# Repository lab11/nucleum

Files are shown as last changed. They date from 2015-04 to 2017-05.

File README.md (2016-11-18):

Nucleum
====

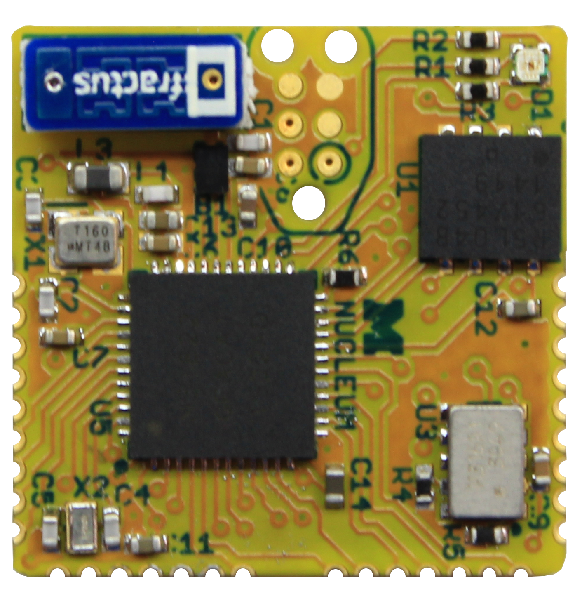
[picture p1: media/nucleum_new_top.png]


Nucleum is a ½ inch² drop-in sensor node module designed to enable rapid
prototyping of Bluetooth Low Energy embedded devices. 
The core of Nucleum is the NRF51822
SoC with an Arm Cortex M0 and BLE radio stack. Nucleum also includes an
antenna, 4 kilo-bytes of non-volatile FRAM memory, an RTC, and a tri-color LED.

Nucleum is designed to have two different usage patterns. First, three sides
of the device have castellated headers allowing Nucleum to be directly
soldered onto a carrier PCB. Nucleum handles all of the computation and
communication while the carrier board supplies power and attaches
sensors or other peripherals. In the second option, Nucleum can function
as a complete sensor node. On the bottom are pads for a regulator
and a battery. If needed, a peripheral or sensor board can be stacked on
top using the headers as a bridge.

History
-------

Nucleum is directly derived from [Atum](http://www.github.com/lab11/atum). It
changes the radio protocol to BLE and adds an on-board programmer. Like Atum, 
it is intended to be a building block for sensor platforms that only includes
the features that a sensor board needs.
Visit the [Atum](http://www.github.com/lab11/atum) page to read more about its 
origins.

Name
----

Nucleum is the latin accusative form of 'Nucleus' which, like [Atum](http://www.github.com/lab11/atum),
represents a basic building block of matter. The 'LE' in the spelling of Nucleum 
indicates its use as a Bluetooth Low Energy prototyping board, and the 'UM' at
the end of Nucleum represents Nucleum's development at the University of Michigan.

Usage
-----

To use the NRF51822, you should run bare metal code that is built around
the Nordic SDK and software BLE stack (known as a softdevice). We provide
some examples and drivers for the chips on the Nucleum board. For more information
on getting started please see software/README.md.

PCB
---

Nucleum PCBs are panelized into 5x8 panels. They are designed to be 
1mm thick to allow for easy soldering of the castellations on the edge of
the board.

If you use the battery and regulator on the bottom of the board, you will have
to populate a 0 Ohm resistor to select regulated voltage. The selection is between 1.8V
and 3.0V. Position A is 1.8V and position B is 3.0V. The 1.8V selection was included
because it significantly lowers power draw on the NRF51822, but at this voltage
the RTC and FRAM may not work. Please see the
[hardware pdf](https://github.com/lab11/nucleum/raw/master/hardware/nucleum/rev_a/nucleum.pdf)
to locate this resistor selector.
DO NOT populate both position A and B; this will short the battery.

Pin Out
-------

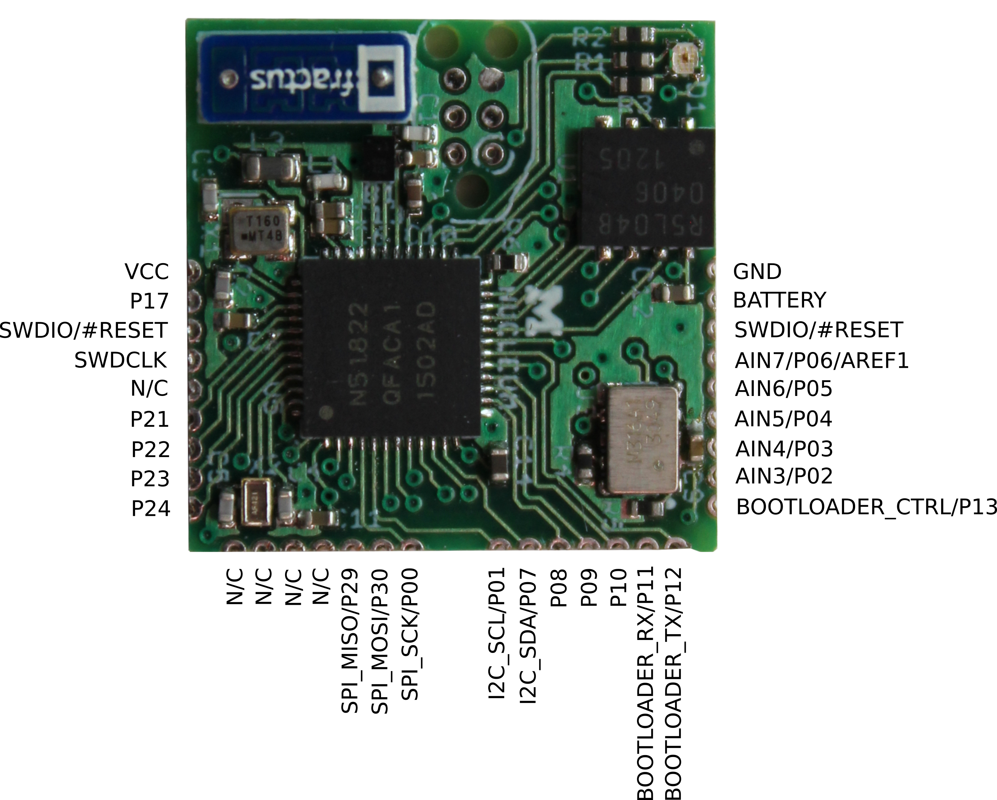
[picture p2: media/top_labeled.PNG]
Nucleum


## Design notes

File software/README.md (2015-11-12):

Getting Started on the nRF51822
===============================

This guide explains how to install the tools necessary to develop for
the nRF51822.

Install the Toolchain
---------------------

The NRF51822 run an ARM Cortex-M0, therefore the [gcc-arm-embedded](https://launchpad.net/gcc-arm-embedded/+download)
compiler will be used. Put the binaries for your platform in the bin directory.

On Linux you will also need 32 bit libs if you don't have them:

	sudo apt-get install lib32z1 lib32ncurses5 lib32bz2-1.0

Test that you have the toolchain by running:
	
	arm-none-eabi-gcc --version

Get a programmer setup
----------------------

Currently we support programming over SWD using a [tag-connect pogo pin header](http://www.tag-connect.com/catalog/6),
and a [j-link](https://www.segger.com/jlink-debug-probes.html) programmer.
We will soon provide a uart bootloader, however a j-link is still necessary to flash
the bootloader.

You should Download and install the [Segger flashing tools](https://www.segger.com/jlink-software.html)
for your platform.

Flash the example program
-------------------------
To flash the example program on to Nucleum:

    make flash 
	
This will automatically add the softdevice if it is not already
on the nRF51822.

For a complete set of commands including erasing and debugging, 
see the nrf51-pure-gcc-setup README.

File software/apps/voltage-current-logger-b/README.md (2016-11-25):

Log Current and Votlage Measurements with Nucleum Logger
========================================================

*This code only works with version B of the cvsense board*
If you want to use version A, then use the app voltage-current-logger

To use this logger:

1) Insert Battery
2) Make flash to update time
3) Insert SD Card
4) Deploy

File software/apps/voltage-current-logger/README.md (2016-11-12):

Log Current and Votlage Measurements with Nucleum Logger
========================================================

According to the creator:

> Yeah. You need to make flash
> Updates the time
> Order is
> - Insert battery
> - Make flash
> - Insert sd card
> - Deploy

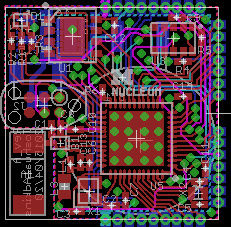
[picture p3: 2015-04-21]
hardware/nucleum/rev_a/nucleum_pcb.png

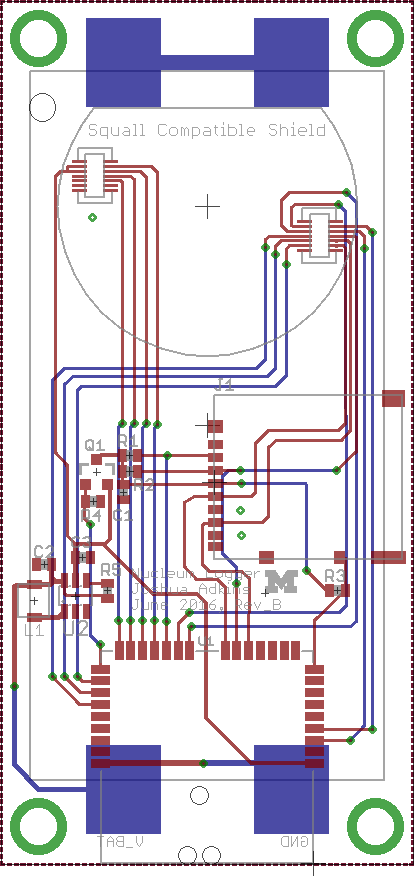
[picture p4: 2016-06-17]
hardware/nucleum_logger/rev_B/nucleum_logger_pcb.png

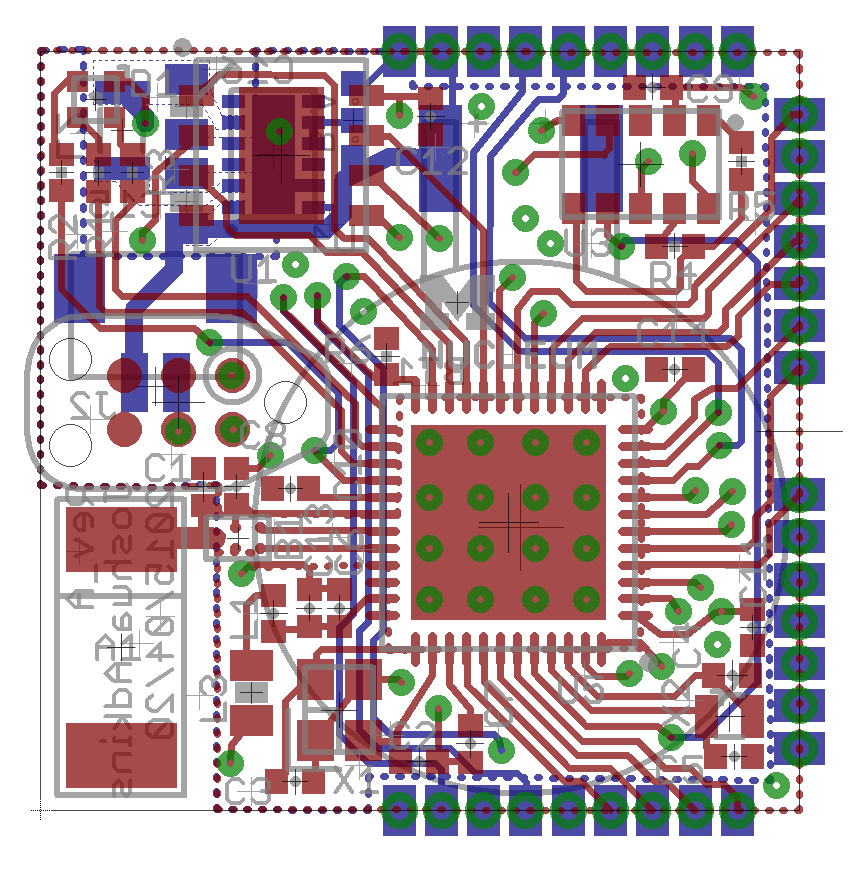
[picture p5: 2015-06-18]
media/nucleum_pcb.png

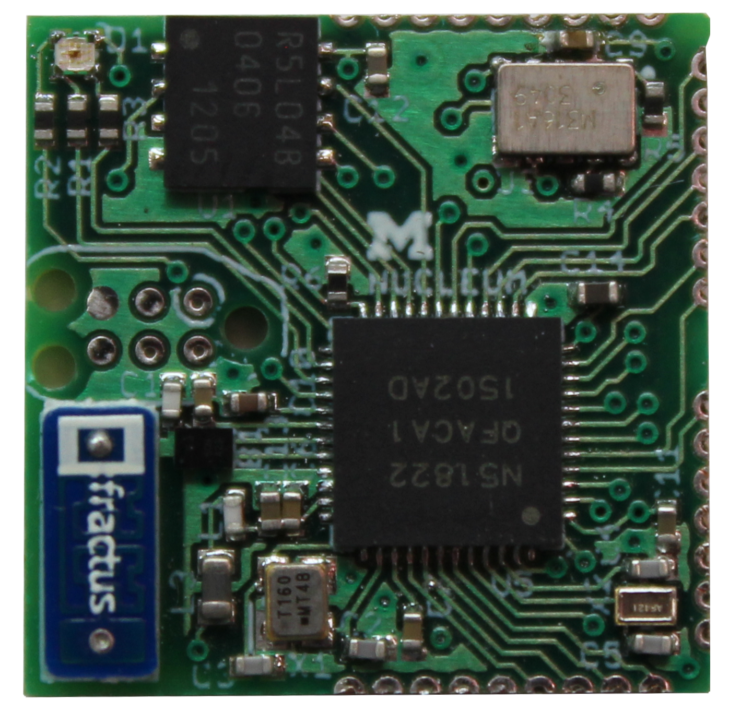
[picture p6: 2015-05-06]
media/nucleum.PNG

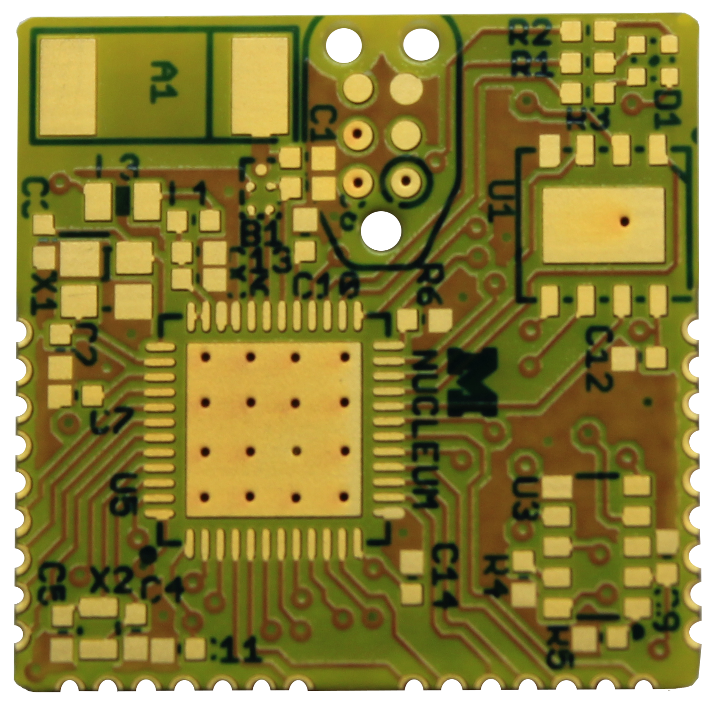
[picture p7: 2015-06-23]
media/nucleum_new.png

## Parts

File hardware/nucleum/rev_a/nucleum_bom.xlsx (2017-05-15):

Qty | Part | Value | Device | Package | DIGIKEY | MOUSER | NEWARK | RICHARDSON_RFPD
1 | A1 | FRACTUS-2.4GHZ-FR05-S1-N-0-102 | FRACTUS-2.4GHZ-FR05-S1-N-0-102 | FRACTUS-ANTENNA-FR05-S1-N-0-102 |  |  |  | FR05-S1-N-0102B
1 | B1 | BAL-NRF01D3 | BAL-NRF01D3 | BAL-NRF01D3 | 497-13637-1-ND | 511-BAL-NRF01D3
1 | DNP | ML-1220/F1AN | ML-1220/F1AN | ML-1220/F1BN | P663-nd | 658-ML-1220/F1BN
1 | C1 | 0.8pF | CAPACITOR | 0402_CAP | 490-6269-1-ND
4 | C2, C3, C4, C5 | 12pF | CAPACITOR | 0402_CAP | 490-6197-1-ND
2 | C6, C7 | 1nF | CAPACITOR | 0402_CAP | 490-1303-1-ND
1 | C8 | 2.2nF | CAPACITOR | 0402_CAP | 490-5419-1-ND
1 | C9 | 10nF | CAPACITOR | 0402_CAP | 445-1260-1-ND
1 | C10 | 47nF | CAPACITOR | 0402_CAP | 445-1264-1-ND
2 | C11, C12 | 0.1uF | CAPACITOR | 0402_CAP | 445-1265-1-ND
1 | C13 | 1uF | CAPACITOR | 0402_CAP | 445-4998-1-ND
1 | C14 | 4.7uF | CAPACITOR | 0402_CAP | 445-5947-1-ND
2 | DNP | 10uF | CAPACITOR0603_CAP | 0603_CAP | 490-7316-1-ND
1 | D1 | SML-LX0404SIUPGUSB | SML-LX0404SIUPGUSB | 1MM_SQ_4PAD | 67-2125-1-ND
1 | DNP | SH_MALE_2/1MM | SH_MALE_2/1MM | SH-1X2/1MM
1 | L1 | 15nH | INDUCTOR0402 | 0402_IND | 587-1521-1-ND
1 | DNP | 2.2uH | INDUCTOR0603 | 0603_IND
1 | L3 | 10uH | INDUCTOR0603 | 0603_IND | 490-4025-1-ND
3 | R1, R2, R3 | 1k | RESISTOR0402_RES | 0402_RES | RHM1.0KCECT-ND
2 | R4, R5 | 10k | RESISTOR0402_RES | 0402_RES | RHM10KCECT-ND
1 | R6 | 12k | RESISTOR0402_RES | 0402_RES | RHM12.0KCDCT-ND
1 | DNP | RES_SWITCH-0k | RES_SWITCH | RES_SWITCH
1 | U2 | FM25LBTDFN-8 | FM25LBTDFN-8 | TDFN-8 | FM25L04B-DGRA-ND | 877-FM25L04B-DG
1 | U3 | RV-3049-C3 | RV-3049-C3 | MICRO-CRYSTAL-C3 |  |  | 09X0513
1 | DNP | TPS62740 | TPS62740 | R-PWSON-12 | 296-37134-1-ND | 595-TPS62740DSST | 27X9745
1 | U5 | NRF51822QF | NRF51822QF | QFN-48-6MM | 1490-1040-1-ND | 949-NRF51822-QFAB-R7
1 | X1 | 16MHz | TXC-8Y | TXC-8Y | 887-2003-1-ND
1 | X2 | ABS05-32.768KHZ-T | ABS05-32.768KHZ-T | ABS05 | 535-11899-1-ND

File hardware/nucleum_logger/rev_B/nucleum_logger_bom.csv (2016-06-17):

# Bill of Materials
# Converted from nucleum_logger_bom.xlsx
# Generated by bom_to_text.py
Part | Value | Device | Package | Description | DIGIKEY | MOUSER | NEWARK
C1 | 4.7uF | CAPACITOR0603_CAP | 0603_CAP | 0402 Capacitor
C2 | 4.7uF | CAPACITOR0603_CAP | 0603_CAP | 0402 Capacitor
C3 | 4.7uF | CAPACITOR0603_CAP | 0603_CAP | 0402 Capacitor
J1 | DM3AT-SF-PEJM5 | DM3AT-SF-PEJM5 | DM3AT-SF-PEJM5 | CONN MICRO SD R/A PUSH-PUSH SMD | HR1964CT-ND
J2 | AA_BAT_PACKSMD | AA_BAT_PACKSMD | AA_SMD | Types of AA Battery Packs | 36-1012-ND
J3 | SQUALL_HEADER_BASE | SQUALL_HEADER_BASE | SQUALL_CARRIER | Header for a sensor board on top of the Squall BLE tag board. | H11616CT-ND
L1 | 4.7uH | INDUCTORVLF3012A | VLF3012A | A very specific inductor | 445-3225-1-ND
LOGO1 | UMICH_SOLID_SMALL | UMICH_SOLID_SMALL | UMICH_SOLID_75MIL
Q1 | NX3008PBK | NX3008PBK | SOT23-3 | MOSFET - P Channel | 568-10499-1-ND | 771-NX3008PBK,215 | 74T4665
R1 | 10K | RESISTOR | 0603-RES | Resistor
R2 | 10K | RESISTOR | 0603-RES | Resistor
R3 | 10K | RESISTOR | 0603-RES | Resistor
R4 | 10K | RESISTOR | 0603-RES | Resistor
R5 | 100K | RESISTOR | 0603-RES | Resistor
U1 | NUCLEUM | NUCLEUM | NUCLEUM | Nucleum sensorboard prototyping module.
U2 | 3.3V | AAT12173.3V | SOT-23-6 | A Simple boost converter | 863-1496-1-ND

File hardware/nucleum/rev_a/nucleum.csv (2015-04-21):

Part | Value | Device | Package | Description | DIGIKEY | MOUSER | NEWARK | RICHARDSON_RFPD
A1 | FRACTUS-2.4GHZ-FR05-S1-N-0-102 | FRACTUS-2.4GHZ-FR05-S1-N-0-102 | FRACTUS-ANTENNA-FR05-S1-N-0-102 | Fractus Compact Reach XtendTM chip antenna is engineered specifically for Bluetooth, |  |  |  | FR05-S1-N-0102B
B1 | BAL-NRF01D3 | BAL-NRF01D3 | BAL-NRF01D3 | 50 ohm nominal input / conjugate match balun to nRF51422-QFAA, | 497-13637-1-ND | 511-BAL-NRF01D3
BT1 | ML-1220/F1AN | ML-1220/F1AN | ML-1220/F1BN | BATTERY LITH 3V RECHARGE PC PINS | P663-nd | 658-ML-1220/F1BN
C1 | 0.8pF | CAPACITOR | 0402_CAP | 0402 Capacitor
C2 | 12pF | CAPACITOR | 0402_CAP | 0402 Capacitor
C3 | 12pF | CAPACITOR | 0402_CAP | 0402 Capacitor
C4 | 12pF | CAPACITOR | 0402_CAP | 0402 Capacitor
C5 | 12pF | CAPACITOR | 0402_CAP | 0402 Capacitor
C6 | 1nF | CAPACITOR | 0402_CAP | 0402 Capacitor
C7 | 1nF | CAPACITOR | 0402_CAP | 0402 Capacitor
C8 | 2.2nF | CAPACITOR | 0402_CAP | 0402 Capacitor
C9 | 10nF | CAPACITOR | 0402_CAP | 0402 Capacitor
C10 | 47nF | CAPACITOR | 0402_CAP | 0402 Capacitor
C11 | 0.1uF | CAPACITOR | 0402_CAP | 0402 Capacitor
C12 | 0.1uF | CAPACITOR | 0402_CAP | 0402 Capacitor
C13 | 1uF | CAPACITOR | 0402_CAP | 0402 Capacitor
C14 | 4.7uF | CAPACITOR | 0402_CAP | 0402 Capacitor
C15 | 10uF | CAPACITOR0603_CAP | 0603_CAP | 0402 Capacitor | 490-7316-1-ND
C16 | 10uF | CAPACITOR0603_CAP | 0603_CAP | 0402 Capacitor | 490-7316-1-ND
D1 | SML-LX0404SIUPGUSB | SML-LX0404SIUPGUSB | 1MM_SQ_4PAD | 1mm^2 RGB LED | 67-2125-1-ND
J1 | TC2030-JLINK-NL | TC2030-JLINK-NL | TC2030-IDC-NL
J2 | SH_MALE_2/1MM | SH_MALE_2/1MM | SH-1X2/1MM | 1.0mm pitch/Disconnectable Crimp style connectors | 455-1788-2-ND
J3 | ATUM-HEADER | ATUM-HEADER | ATUM-HEADER | Castellated header for the Atum board.
L1 | 15nH | INDUCTOR0402 | 0402_CAP
L2 | 2.2uH | MIPSZ2012D | MIPSZ201D | FDK Multi-layer Power Inductor : MIPSZ2012D series (Very Small Type)
L3 | 10uH | INDUCTOR0603 | 0603_CAP
LOGO1 | UMICH_SOLID_TINY | UMICH_SOLID_TINY | UMICH_SOLID_50MIL
R1 | 1k | RESISTOR0402_RES | 0402_RES | Resistor
R2 | 1k | RESISTOR0402_RES | 0402_RES | Resistor
R3 | 1k | RESISTOR0402_RES | 0402_RES | Resistor
R4 | 10k | RESISTOR0402_RES | 0402_RES | Resistor
R5 | 10k | RESISTOR0402_RES | 0402_RES | Resistor
R6 | 12k | RESISTOR0402_RES | 0402_RES | Resistor
S1 | RES_SWITCH | RES_SWITCH | RES_SWITCH | 0402 Static Resistor Selector
U2 | FM25LBTDFN-8 | FM25LBTDFN-8 | TDFN-8 | IC FRAM 4KBIT 10MHZ 8SOIC | FM25L04B-DGRA-ND | 877-FM25L04B-DG
U3 | RV-3049-C3 | RV-3049-C3 | MICRO-CRYSTAL-C3 | The RV-3049-C3 is an ultra miniature Real-Time-Clock Module
U4 | TPS62740 | TPS62740 | R-PWSON-12 | 360nA Step Down Converter for Low Power Applications | 296-37134-1-ND | 595-TPS62740DSST | 27X9745
U5 | NRF51822QF | NRF51822QF | QFN-48-6MM | Multiprotocol Bluetooth® 4.0 low energy/2.4 GHz RF SoC | 1490-1032-1-ND | 949-NRF51822-QFAB-R7
X1 | EPSON-FA-128 | EPSON-FA-128 | FA-128 | MHz RANGE CRYSTAL UNIT
X2 | ABS05-32.768KHZ-T | ABS05-32.768KHZ-T | ABS05 | 32.768kHz Crystal | 535-11899-1-ND

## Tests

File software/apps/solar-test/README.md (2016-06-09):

This folder stores the firmware to test and store data recorded by the pressure sensor
on the Monoxalyze board. This test is intended to periodically record and
store pressure and temperature data as a test for pressure sensitive wakeup.
The rest of the guide explains how to build and program the NRF51822 running 
on Monoxalyze.

Setup
=====

1. Make sure you have the [arm-none-eabi-gcc](https://launchpad.net/gcc-arm-embedded)
toolchain. You just need the binaries for your platform.

2. Get the nRF51822 SDK and S110 soft device from the
[downloads page](https://www.nordicsemi.com/eng/Products/Bluetooth-Smart-Bluetooth-low-energy/nRF51822?resource=20339).
You want the "nRF51 SDK Zip File" and the "S110 nRF51822 SoftDevice (Production ready)".
You do need to buy a nRF51822 evm kit to get access to these, because companies
are the worst. Edit the SOFTDEVICE variable in the makefile to point to the 
hex file of the softdevice you are using (currently using s110-7.1.0.hex).

3. Get the [Segger flashing tools](http://www.segger.com/jlink-software.html)
for your platform.

4. Get the [nrf51-pure-gcc-setup](http://github.com/lab11/nrf51-pure-gcc-setup).

Install the Application
======================

1. Make sure the path to the SDK is set correctly in the application
makefile (or override it in your environment).

1. Make sure your SDK version is set correctly in the application makefile
(currently support version 6 and version 7)

1. Make sure the path to the TEMPLATE (nrf51-pure-gcc-setup) is set 
correctly in the application makefile. 

1. Now compile and load the application code.

        make flash

Run the Test
============

1. After reset the application will collect 8 hours of pressure and temperature 
Data. The data will start at flash 10k. 

Retrieve the Data
================

1. After the devices has been collecting data for 8 hours run make collect
with the device connected to the JLink to pull the data from the chip,
parse the data into a readable csv, and save it in a data folder

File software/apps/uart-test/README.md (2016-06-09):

UART Test
=========

App that prints data to UART lines.

By default uses the BTLDR_TX and BTLDR_RX on the Nucleum breakout.

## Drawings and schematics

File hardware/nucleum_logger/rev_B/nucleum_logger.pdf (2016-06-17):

## P25_1 SDA

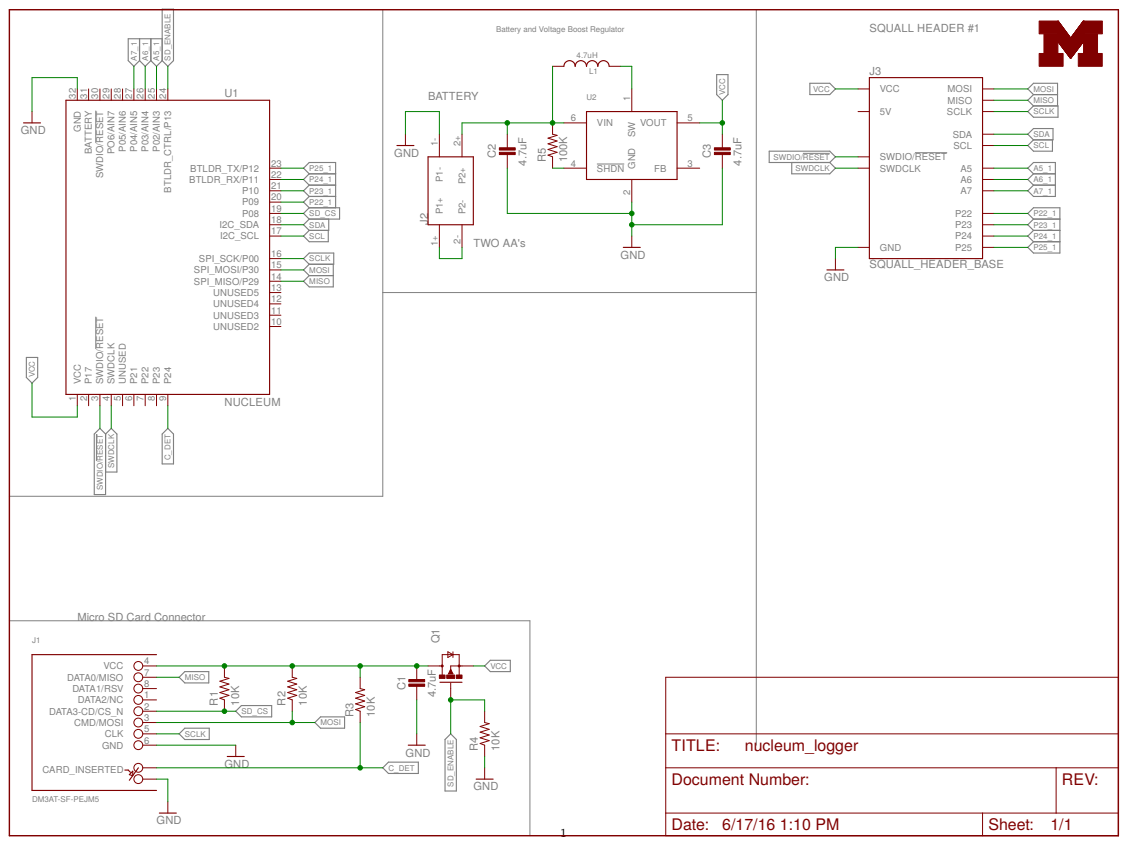
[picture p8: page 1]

Battery and Voltage Boost Regulator

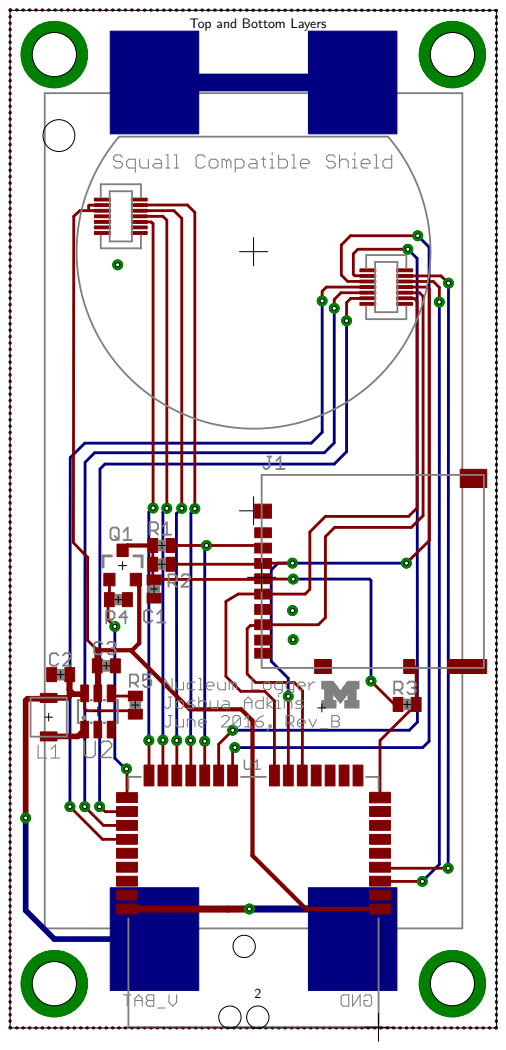
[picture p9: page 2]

Top and Bottom Layers

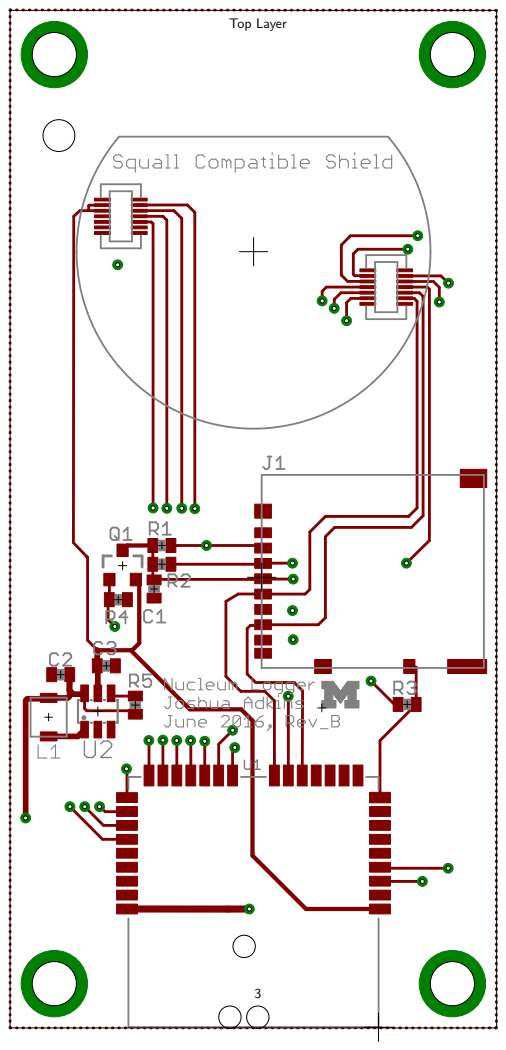
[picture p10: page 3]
Top Layer

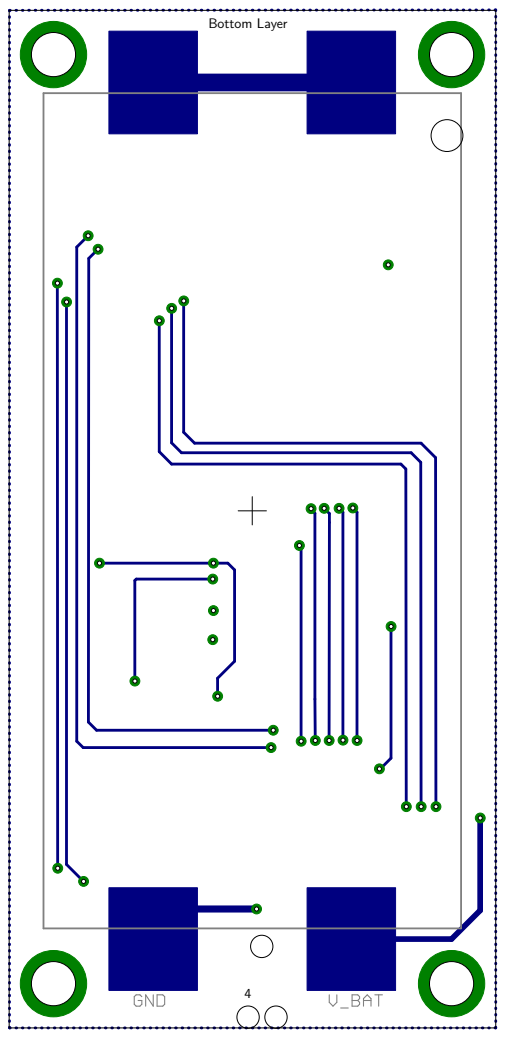
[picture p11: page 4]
Bottom Layer

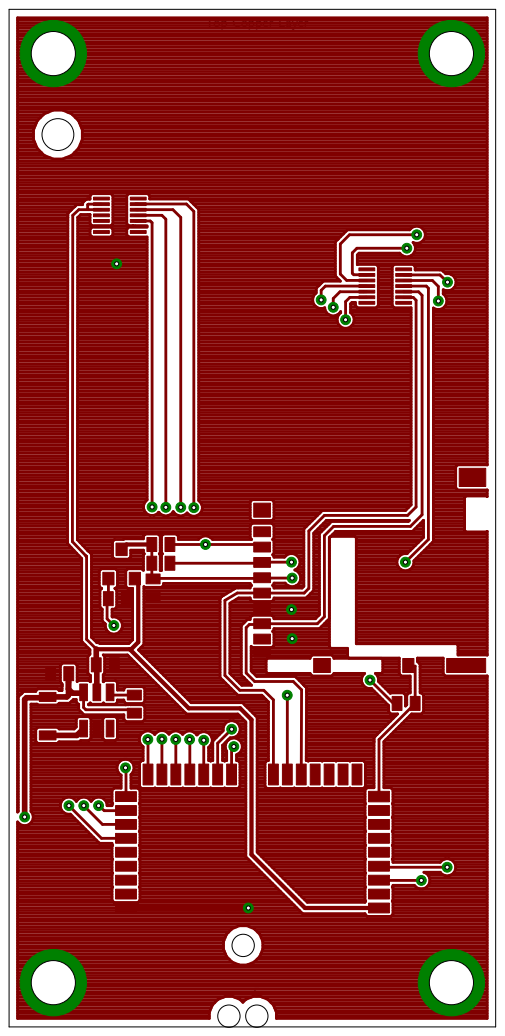
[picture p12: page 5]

Top Copper Layer

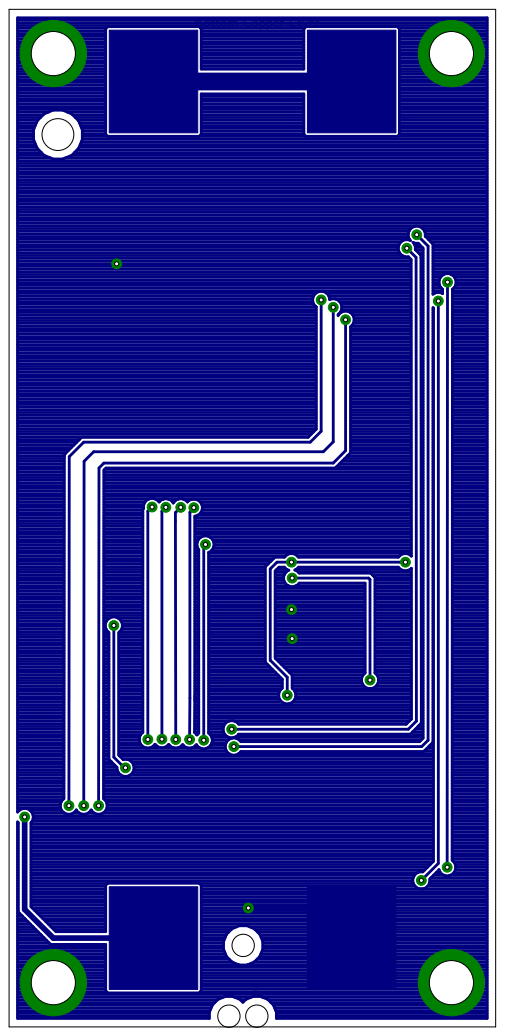
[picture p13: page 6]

Bottom Copper Layer

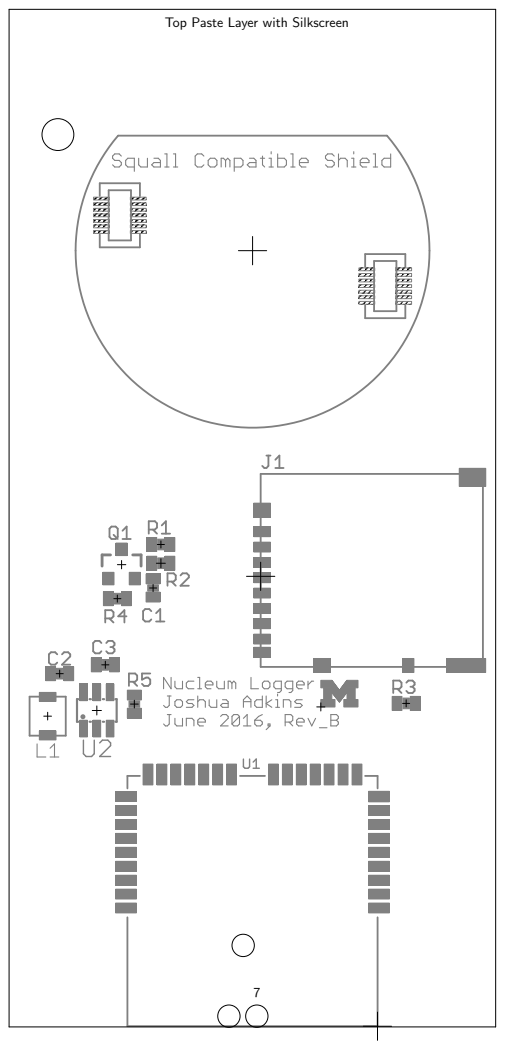
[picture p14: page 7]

Top Paste Layer with Silkscreen

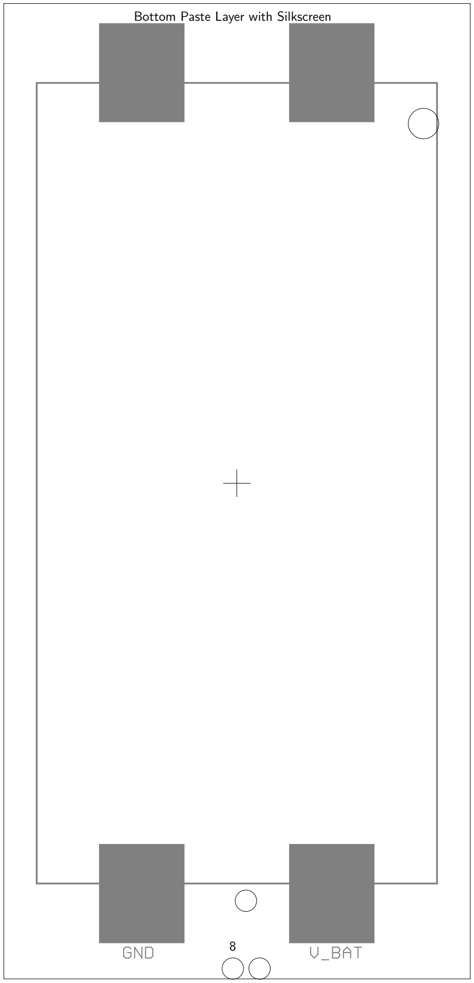
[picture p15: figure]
Bottom Paste Layer with Silkscreen
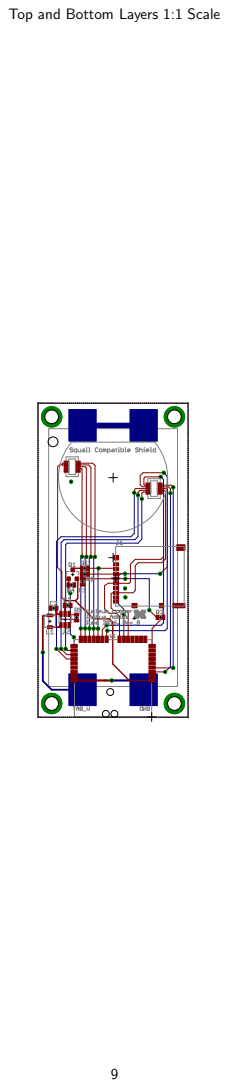
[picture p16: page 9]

Top and Bottom Layers 1:1 Scale

Top Layer 1:1 Scale

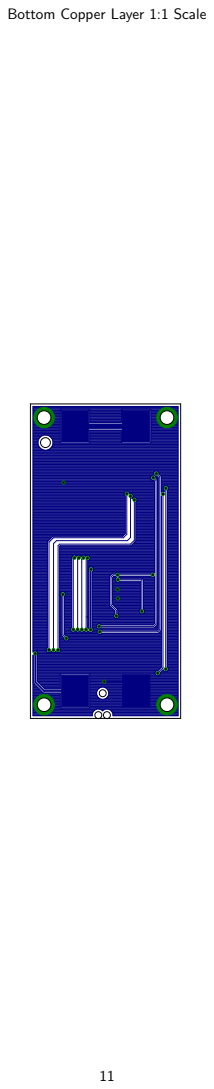
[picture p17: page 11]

Bottom Copper Layer 1:1 Scale

### nucleum_logger

Part | Value | Device | Package
C1 | 4.7uF | CAPACITOR0603_CAP | 0603_CAP
C2 | 4.7uF | CAPACITOR0603_CAP | 0603_CAP
C3 | 4.7uF | CAPACITOR0603_CAP | 0603_CAP
J1 | DM3AT-SF-PEJM5 | DM3AT-SF-PEJM5 | DM3AT-SF-PEJM5
J2 | AA_BAT_PACKSMD | AA_BAT_PACKSMD | AA_SMD
J3 | SQUALL_HEADER_BASE SQUALL_HEADER_BASE SQUALL_CARRIER
L1 | 4.7uH | INDUCTORVLF3012A | VLF3012A
LOGO1 UMICH_SOLID_SMALL | UMICH_SOLID_SMALL | UMICH_SOLID_75MIL
Q1 | NX3008PBK | NX3008PBK | SOT23-3
R1 | 10K | RESISTOR | 0603-RES
R2 | 10K | RESISTOR | 0603-RES
R3 | 10K | RESISTOR | 0603-RES
R4 | 10K | RESISTOR | 0603-RES
R5 | 100K | RESISTOR | 0603-RES
U1 | NUCLEUM | NUCLEUM | NUCLEUM
U2 | 3.3V | AAT12173.3V | SOT-23-6

### nucleum_logger

Description | DIGIKEY | MOUSER
0402 Capacitor
0402 Capacitor
0402 Capacitor
CONN MICRO SD R/A PUSH-PUSH SMD | HR1964CT-ND
Types of AA Battery Packs | 36-1012-ND
Header for a sensor board on top of the Squall BLE tag board. | H11616CT-ND
A very specific inductor | 445-3225-1-ND
MOSFET - P Channel | 568-10499-1-ND 771-NX3008PBK,215
Resistor
Resistor
Resistor
Resistor
Resistor
Nucleum sensorboard prototyping module.
A Simple boost converter | 863-1496-1-ND

### nucleum_logger

NEWARK

74T4665

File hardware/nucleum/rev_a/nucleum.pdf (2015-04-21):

# SPI_SCK RTC_INT

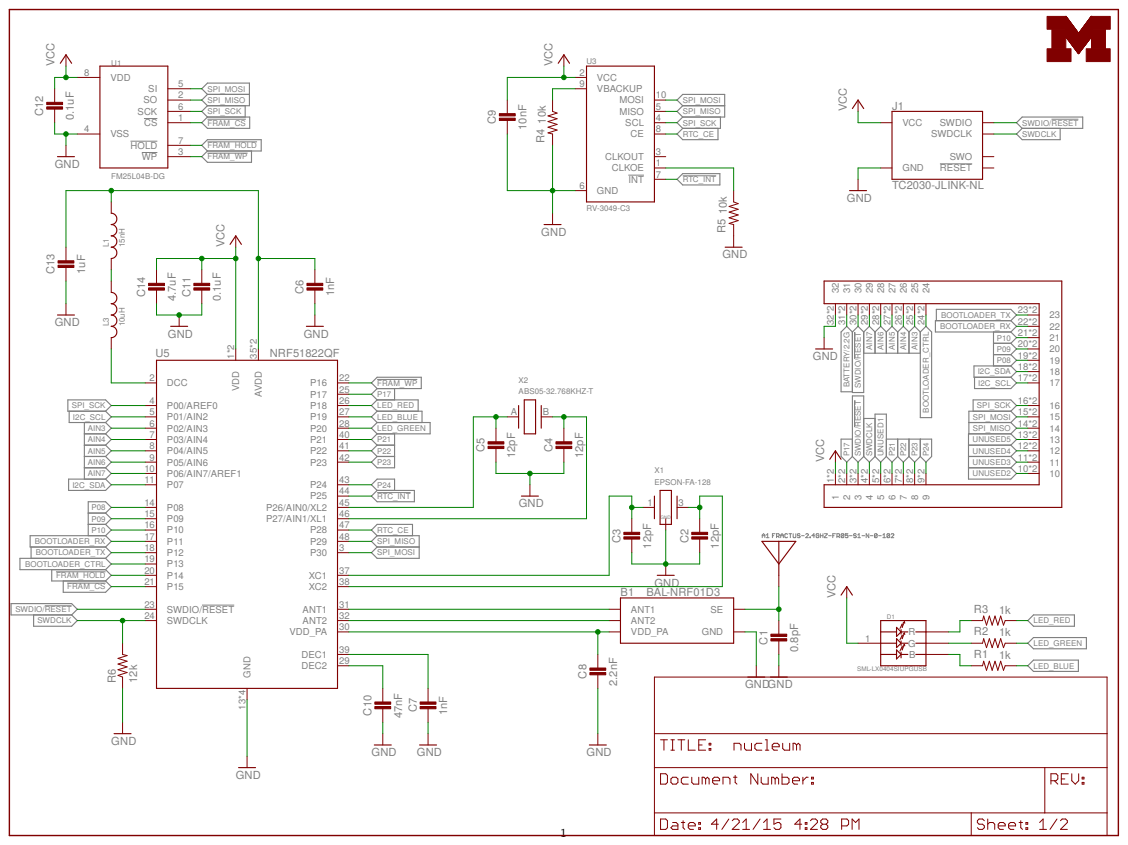
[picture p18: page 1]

SWDIO/RESET

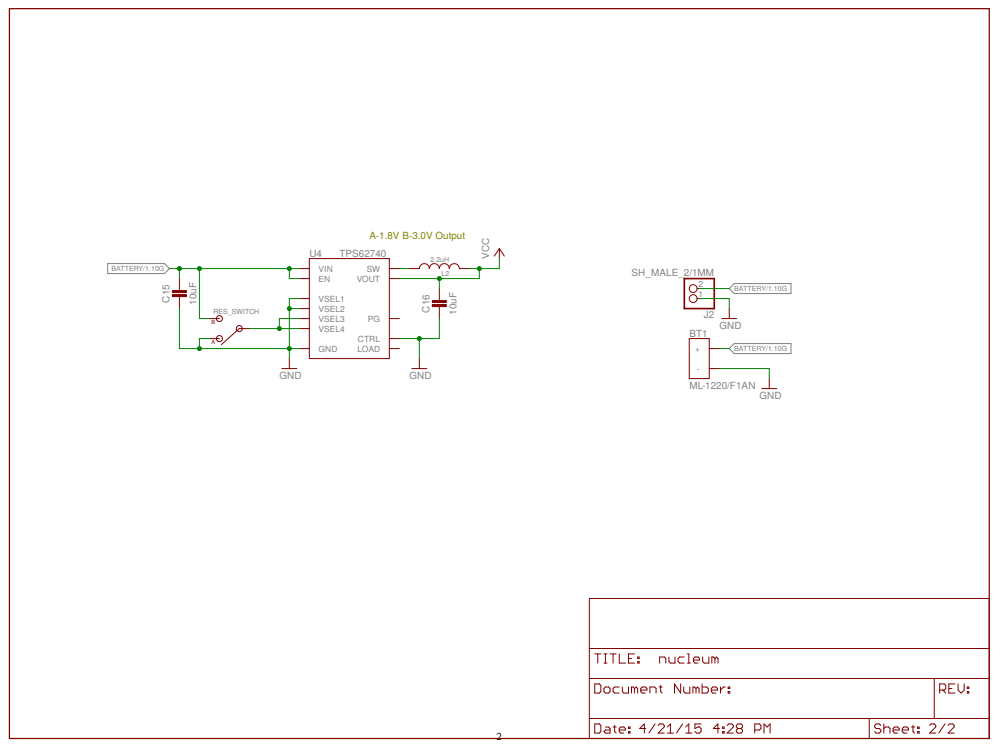
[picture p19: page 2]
2 A-1.8V B-3.0V Output TPS62740 GND; GND².2uH; VCC; ML-1220/F1AN GND ¹⁰uF; SH_MALE_2/1MM GND RES_SWITCH; SW VOUT PG CTRL GND; LOAD VSEL4 VSEL3 VSEL2 VSEL1 ENVIN U4; +- BT1 C¹⁵; C¹⁶; J2 ¹² BATTERY/1.10G; BATTERY/1.10G BATTERY/1.10G AB

# Top and Bottom Layers 3 A B


Top Layer

# Bottom Layer 5 A B



Top Copper Layer

Layer 2 Copper

Layer 3 Copper


Bottom Copper Layer


Top Paste Layer with Silkscreen

Bottom Paste Layer with Silkscreen


Top and Bottom Layers 1:1 Scale

Top Layer 1:1 Scale

Layer 2 Copper 1:1 Scale

Layer 3 Copper 1:1 Scale


Bottom Copper Layer 1:1 Scale

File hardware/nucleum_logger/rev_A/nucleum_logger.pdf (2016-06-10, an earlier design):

## SCLA5A6A7 P22 P23 P24 P25


Nucleum Logger Rev_A Joshua Adkins - Lab11 June 2016

Top and Bottom Layers

BLEES Compatible Shield

Top Layer; Nucleum Logger Rev_A Joshua Adkins - Lab11 June 2016

BLEES Compatible Shield

Bottom Layer


Top Copper Layer


Bottom Copper Layer

Top Paste Layer with Silkscreen; BLEES Compatible Shield; Nucleum Logger Rev_A Joshua Adkins - Lab11 June 2016

Bottom Paste Layer with Silkscreen
Nucleum Logger Rev_A Joshua Adkins - Lab11 June 2016

Top and Bottom Layers 1:1 Scale

BLEES Compatible Shield

Top Layer 1:1 Scale


Bottom Copper Layer 1:1 Scale

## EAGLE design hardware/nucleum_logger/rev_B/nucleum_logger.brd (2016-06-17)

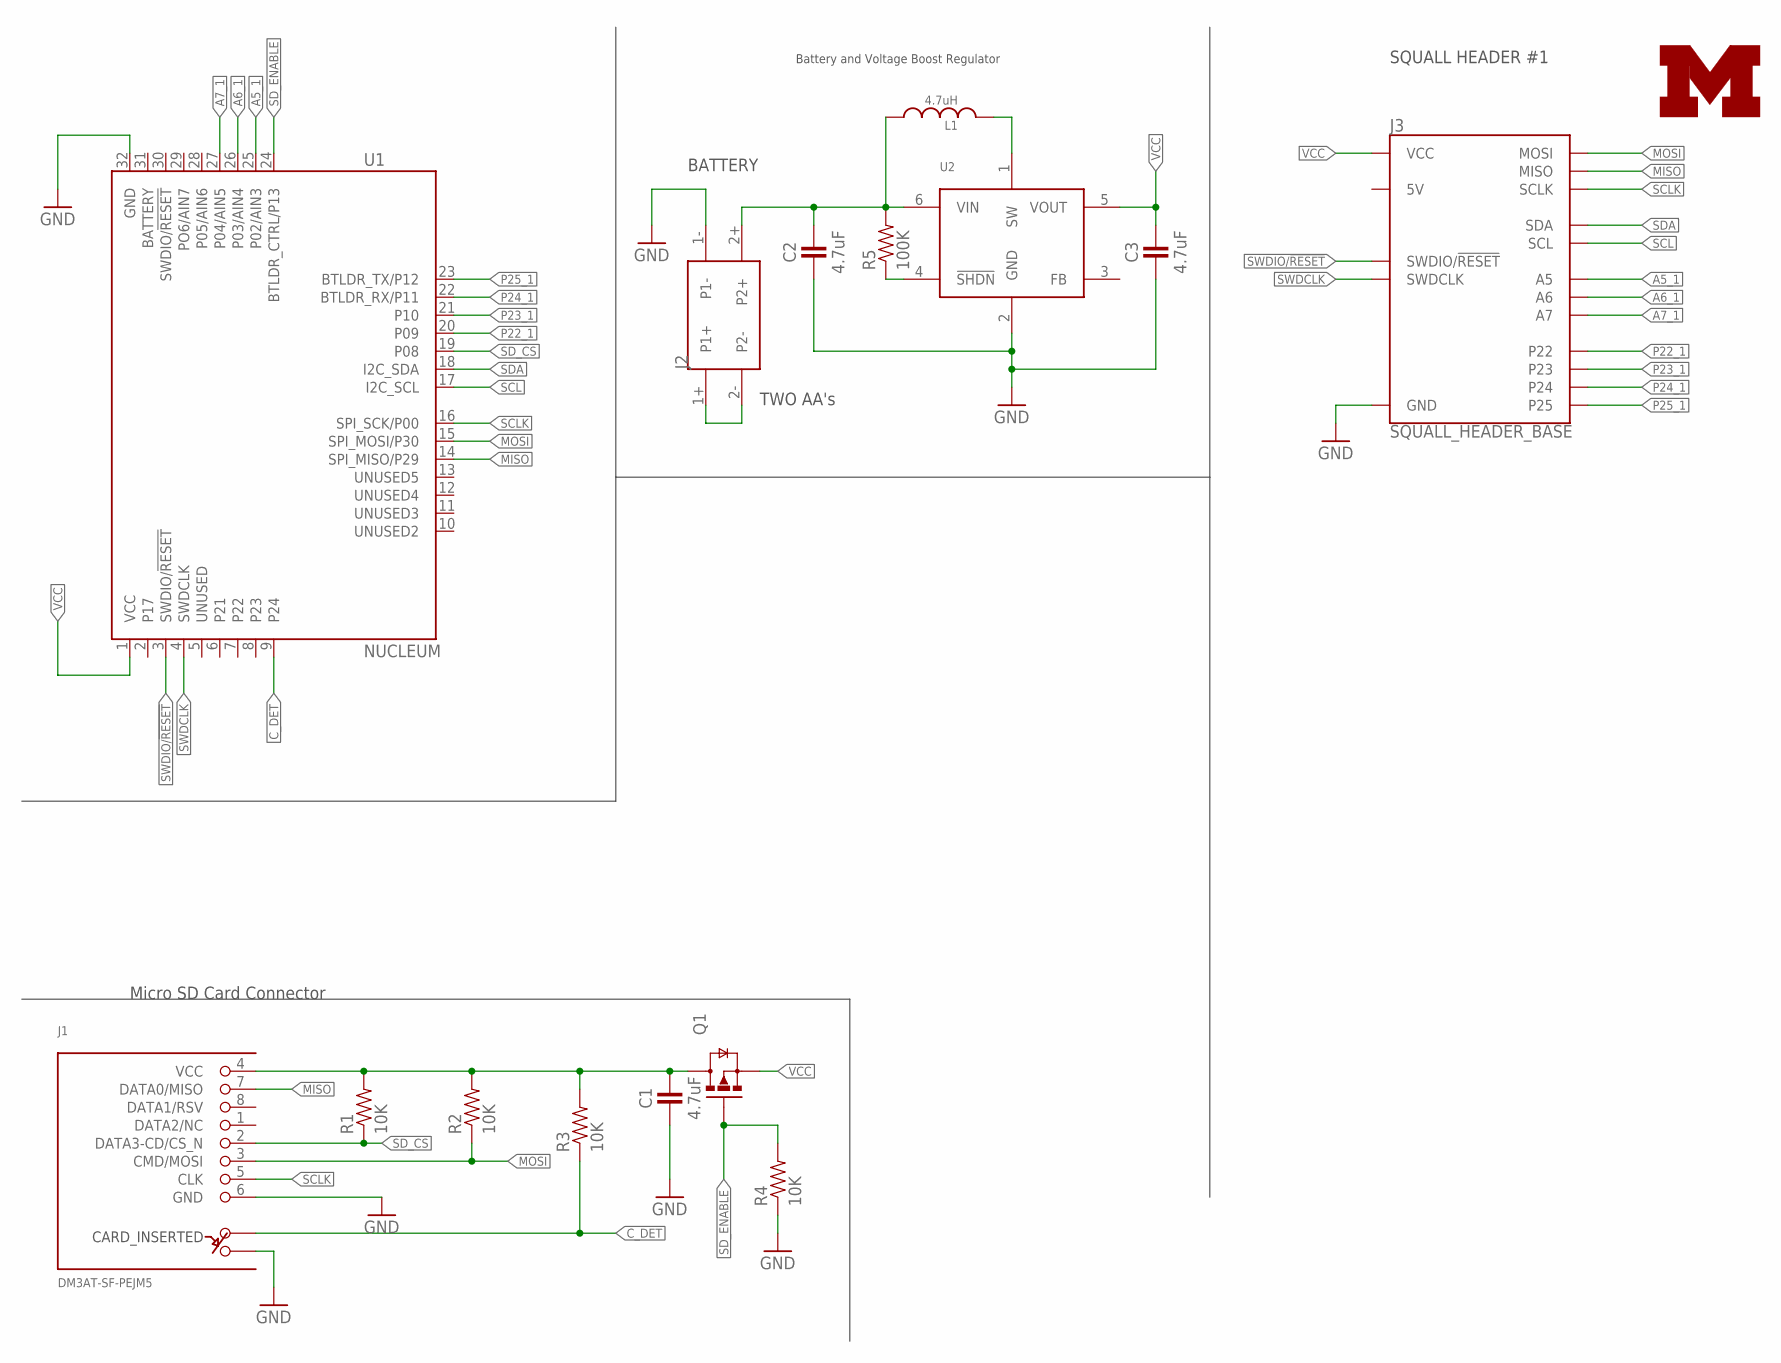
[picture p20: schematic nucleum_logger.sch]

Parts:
C1, C2, C3: 4.7uF; 0603_CAP
J1: DM3AT-SF-PEJM5
J2: AA_BAT_PACKSMD; AA_SMD
J3: SQUALL_HEADER_BASE; SQUALL_CARRIER
L1: 4.7uH; VLF3012A
LOGO1: UMICH_SOLID_SMALL; UMICH_SOLID_75MIL
Q1: NX3008PBK; SOT23-3
R1, R2, R3, R4: 10K; 0603-RES
R5: 100K; 0603-RES
U1: NUCLEUM
U2: AAT12173.3V; SOT-23-6

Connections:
A5_1: J3.B9 (A5), U1.25 (P02/AIN3)
A6_1: J3.B7 (A6), U1.26 (P03/AIN4)
A7_1: J3.B5 (A7), U1.27 (P04/AIN5)
C_DET: J1.A, R3.1, U1.9 (P24)
GND: C1.2, C2.2, C3.2, J1.6 (GND), J1.B, J2.1-, J3.A9 (GND), J3.A10 (GND), R4.1, U1.32 (GND), U2.2 (GND)
MISO: J1.7 (DATA0/MISO), J3.B8 (MISO), U1.14 (SPI_MISO/P29)
MOSI: J1.3 (CMD/MOSI), J3.B6 (MOSI), R2.1, U1.15 (SPI_MOSI/P30)
unnamed: J2.1+, J2.2-
unnamed: R5.1, U2.4 (!SHDN)
unnamed: L1.P$2 (2), U2.1 (SW)
P22_1: J3.A2 (P22), U1.20 (P09)
P23_1: J3.A4 (P23), U1.21 (P10)
P24_1: J3.A6 (P24), U1.22 (BTLDR_RX/P11)
P25_1: J3.A8 (P25), U1.23 (BTLDR_TX/P12)
SCL: J3.B3 (SCL), U1.17 (I2C_SCL)
SCLK: J1.5 (CLK), J3.B10 (SCLK), U1.16 (SPI_SCK/P00)
SDA: J3.B1 (SDA), U1.18 (I2C_SDA)
SD_CS: J1.2 (DATA3-CD/CS_N), R1.1, U1.19 (P08)
SD_ENABLE: Q1.1 (G), R4.2, U1.24 (BTLDR_CTRL/P13)
SWDCLK: J3.B2 (SWDCLK), U1.4 (SWDCLK)
SWDIO/!RESET: J3.B4 (SWDIO/!RESET), U1.3 (SWDIO/!RESET)
VCC: C3.1, J3.A1 (VCC), J3.A3 (VCC), Q1.2 (S), U1.1 (VCC), U2.5 (VOUT)
V_BAT: C2.1, J2.2+, L1.P$1 (1), R5.2, U2.6 (VIN)
V_SD: C1.1, J1.4 (VCC), Q1.3 (D), R1.2, R2.2, R3.2

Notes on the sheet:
Micro SD Card Connector
SQUALL HEADER #1
BATTERY
TWO AA's
Battery and Voltage Boost Regulator

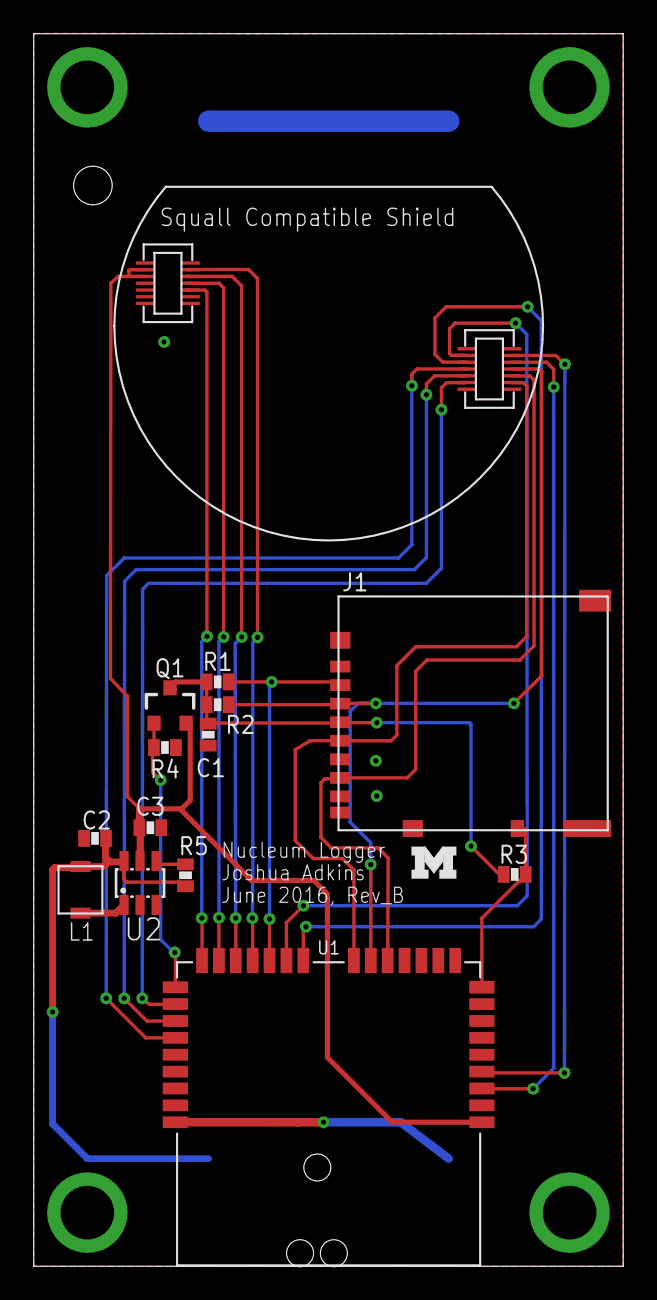
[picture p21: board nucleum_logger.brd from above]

Board: 2 copper layers, 34.9 x 73.0 mm, 16 parts (1 on the bottom side), 24 nets.

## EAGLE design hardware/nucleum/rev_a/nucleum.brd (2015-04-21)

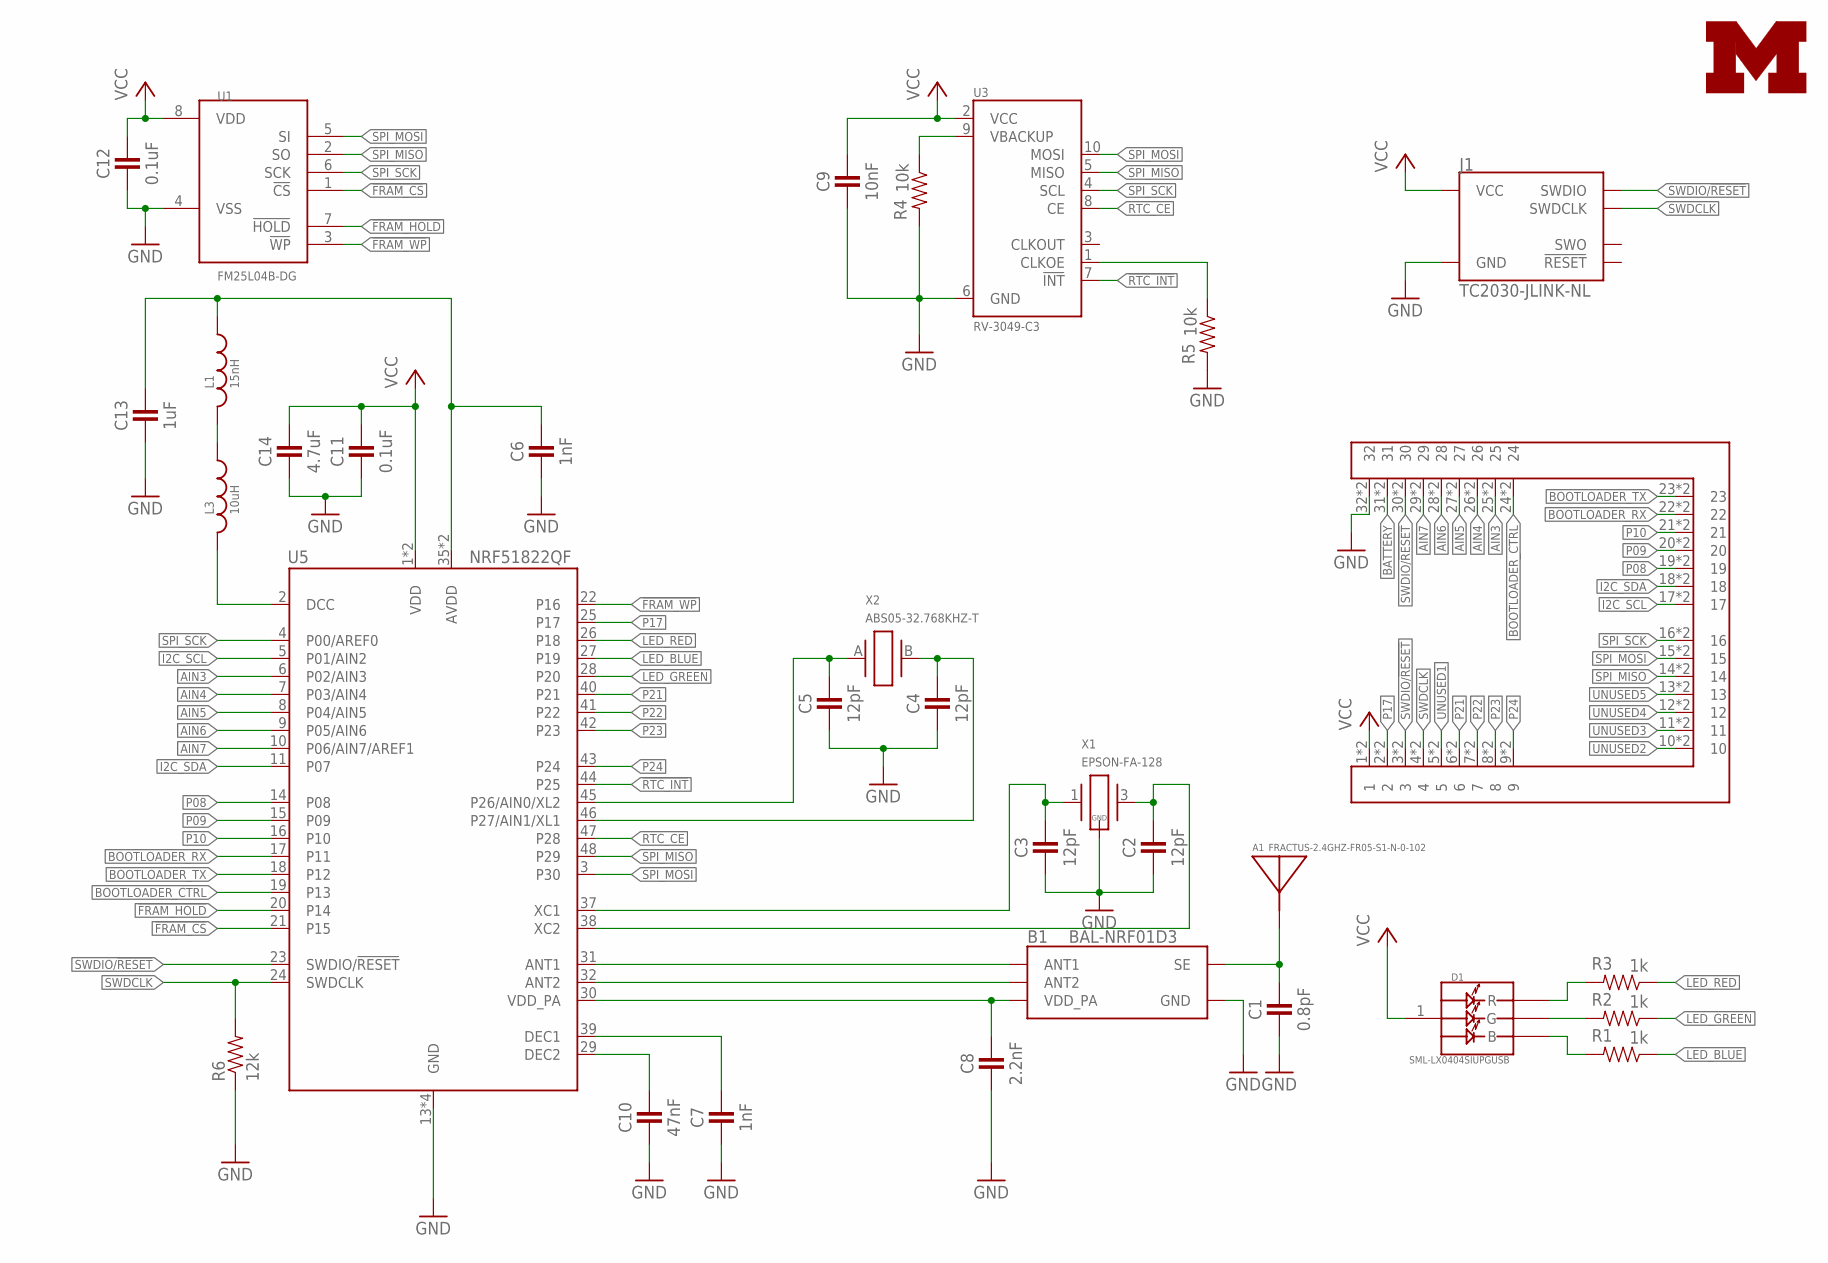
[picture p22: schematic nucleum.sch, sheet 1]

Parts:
A1: FRACTUS-2.4GHZ-FR05-S1-N-0-102; FRACTUS-ANTENNA-FR05-S1-N-0-102
B1: BAL-NRF01D3
C1: 0.8pF; 0402_CAP
C2, C3, C4, C5: 12pF; 0402_CAP
C6, C7: 1nF; 0402_CAP
C8: 2.2nF; 0402_CAP
C9: 10nF; 0402_CAP
C10: 47nF; 0402_CAP
C11, C12: 0.1uF; 0402_CAP
C13: 1uF; 0402_CAP
C14: 4.7uF; 0402_CAP
D1: SML-LX0404SIUPGUSB; 1MM_SQ_4PAD
J1: TC2030-JLINK-NL; TC2030-IDC-NL
J3: ATUM-HEADER
L1: 15nH; 0402_CAP
L3: 10uH; 0603_CAP
LOGO1: UMICH_SOLID_TINY; UMICH_SOLID_50MIL
R1, R2, R3: 1k; 0402_RES
R4, R5: 10k; 0402_RES
R6: 12k; 0402_RES
U1: FM25L04B-DG; TDFN-8
U3: RV-3049-C3; MICRO-CRYSTAL-C3
U5: NRF51822QF; QFN-48-6MM
X1: EPSON-FA-128; FA-128
X2: ABS05-32.768KHZ-T; ABS05

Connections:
!FRAM_CS: U1.1 (!CS), U5.21 (P15)
!FRAM_HOLD: U1.7 (!HOLD), U5.20 (P14)
!FRAM_WP: U1.3 (!WP), U5.22 (P16)
!RTC_INT: U3.7 (!INT), U5.44 (P25)
AIN3: J3.25, J3.25B (25), U5.6 (P02/AIN3)
AIN4: J3.26, J3.26B (26), U5.7 (P03/AIN4)
AIN5: J3.27, J3.27B (27), U5.8 (P04/AIN5)
AIN6: J3.28, J3.28B (28), U5.9 (P05/AIN6)
AIN7: J3.29, J3.29B (29), U5.10 (P06/AIN7/AREF1)
ANTENNA: A1.1, B1.SE, C1.1
BATTERY: J3.31, J3.31B (31); also elsewhere on the board
BOOTLOADER_CTRL: J3.24, J3.24B (24), U5.19 (P13)
BOOTLOADER_RX: J3.22, J3.22B (22), U5.17 (P11)
BOOTLOADER_TX: J3.23, J3.23B (23), U5.18 (P12)
GND: B1.GND, C1.2, C2.2, C3.2, C4.2, C5.2, C6.2, C7.2, C8.2, C9.2, C10.2, C11.2, C12.2, C13.2, C14.2, J1.5 (GND), J3.32, J3.32B (32), R4.2, R5.2, R6.1, U1.4 (VSS), U3.6 (GND), U5.13 (GND), U5.33 (GND), U5.34 (GND), U5.GND, X1.2 (GND), X1.4 (GND); also elsewhere on the board
I2C_SCL: J3.17, J3.17B (17), U5.5 (P01/AIN2)
I2C_SDA: J3.18, J3.18B (18), U5.11 (P07)
LED_BLUE: R1.1, U5.27 (P19)
LED_GREEN: R2.1, U5.28 (P20)
LED_RED: R3.1, U5.26 (P18)
unnamed: C5.1, U5.45 (P26/AIN0/XL2), X2.A (1)
unnamed: D1.2 (R), R3.2
unnamed: C3.1, U5.37 (XC1), X1.1
unnamed: C2.1, U5.38 (XC2), X1.3 (2)
unnamed: D1.4 (G), R2.2
unnamed: D1.3 (B), R1.2
unnamed: C4.1, U5.46 (P27/AIN1/XL1), X2.B (2)
unnamed: R4.1, U3.9 (VBACKUP)
unnamed: C10.1, U5.29 (DEC2)
unnamed: R5.1, U3.1 (CLKOE)
unnamed: C7.1, U5.39 (DEC1)
unnamed: B1.ANT1, U5.31 (ANT1)
unnamed: B1.ANT2, U5.32 (ANT2)
unnamed: B1.VCC (VDD_PA), C8.1, U5.30 (VDD_PA)
unnamed: C6.1, C13.1, L1.1, U5.35 (AVDD), U5.36 (AVDD)
unnamed: L1.2, L3.1
unnamed: L3.2, U5.2 (DCC)
P08: J3.19, J3.19B (19), U5.14 (P08)
P09: J3.20, J3.20B (20), U5.15 (P09)
P10: J3.21, J3.21B (21), U5.16 (P10)
P17: J3.2, J3.2B (2), U5.25 (P17)
P21: J3.6, J3.6B (6), U5.40 (P21)
P22: J3.7, J3.7B (7), U5.41 (P22)
P23: J3.8, J3.8B (8), U5.42 (P23)
P24: J3.9, J3.9B (9), U5.43 (P24)
RTC_CE: U3.8 (CE), U5.47 (P28)
SPI_MISO: J3.14, J3.14B (14), U1.2 (SO), U3.5 (MISO), U5.48 (P29)
SPI_MOSI: J3.15, J3.15B (15), U1.5 (SI), U3.10 (MOSI), U5.3 (P30)
SPI_SCK: J3.16, J3.16B (16), U1.6 (SCK), U3.4 (SCL), U5.4 (P00/AREF0)
SWDCLK: J1.4 (SWDCLK), J3.4, J3.4B (4), R6.2, U5.24 (SWDCLK)
SWDIO/!RESET: J1.2 (SWDIO), J3.3, J3.3B (3), J3.30, J3.30B (30), U5.23 (SWDIO/!RESET)
UNUSED1: J3.5, J3.5B (5)
UNUSED2: J3.10, J3.10B (10)
UNUSED3: J3.11, J3.11B (11)
UNUSED4: J3.12, J3.12B (12)
UNUSED5: J3.13, J3.13B (13)
VCC: C9.1, C11.1, C12.1, C14.1, D1.1 (VDD), J1.1 (VCC), J3.1, J3.1B (1), U1.8 (VDD), U3.2 (VCC), U5.1 (VDD), U5.12 (VDD); also elsewhere on the board

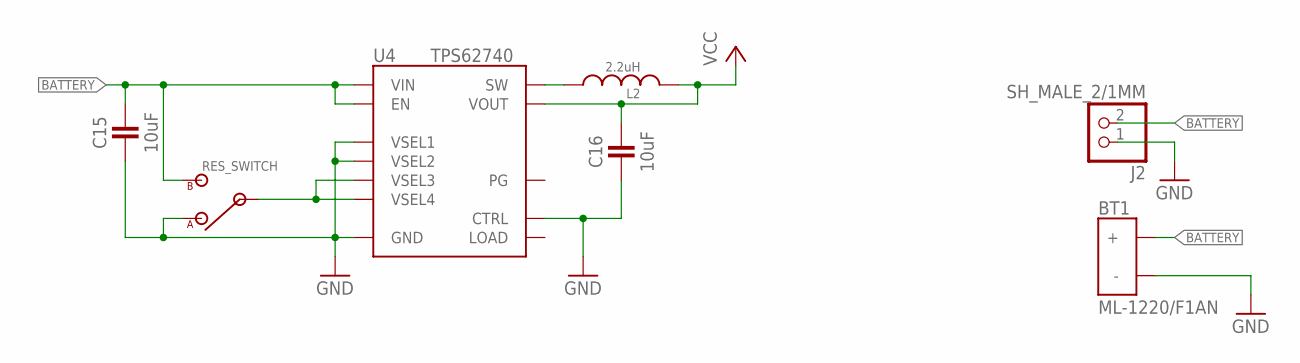
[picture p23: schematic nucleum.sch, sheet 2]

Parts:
BT1: ML-1220/F1AN; ML-1220/F1BN
C15, C16: 10uF; 0603_CAP; DIGIKEY 490-7316-1-ND
J2: SH_MALE_2/1MM; SH-1X2/1MM
L2: 2.2uH; MIPSZ201D
S1: RES_SWITCH
U4: TPS62740; R-PWSON-12

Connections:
BATTERY: BT1.POS (+), C15.1, J2.2, S1.B, U4.1 (VIN), U4.12 (EN); also elsewhere on the board
GND: BT1.NEG (-), C15.2, C16.2, J2.1, S1.A, U4.3 (GND), U4.4 (CTRL), U4.10 (VSEL2), U4.11 (VSEL1), U4.NC (GND); also elsewhere on the board
unnamed: L2.1, U4.2 (SW)
unnamed: S1.C (IN), U4.8 (VSEL4), U4.9 (VSEL3)
VCC: C16.1, L2.2, U4.5 (VOUT); also elsewhere on the board

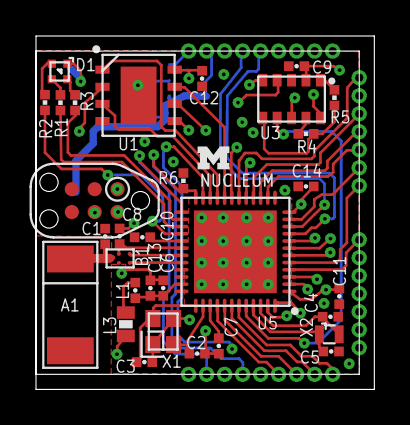
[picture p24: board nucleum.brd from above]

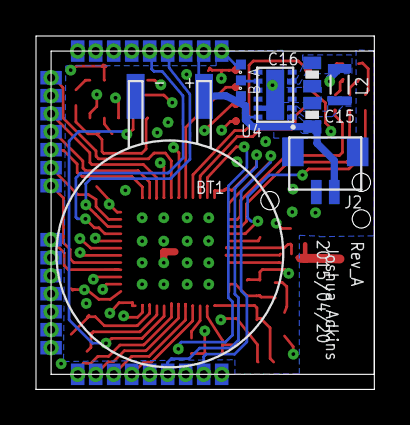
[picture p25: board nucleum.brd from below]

Board: 4 copper layers, 18.8 x 19.6 mm, 40 parts (7 on the bottom side), 59 nets.

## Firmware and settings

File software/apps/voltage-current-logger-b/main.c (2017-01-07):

// Global libraries
#include <stdint.h>

// Nordic libraries
#include "ble_advdata.h"

// nrf5x-base libraries
#include "simple_ble.h"
#include "simple_adv.h"
#include "multi_adv.h"
#include "eddystone.h"
#include "simple_timer.h"
#include "nrf_gpio.h"
#include "led.h"
#include "nucleum_logger.h"
#include "cvsense.h"
#include "rv3049.h"
#include "simple_logger.h"

#define ADV_SWITCH_MS 1000
#define PHYSWEB_URL "goo.gl/qtn9V9"
#define CV_SENSE_SERVICE 0x17
#define UMICH_COMPANY_IDENTIFIER 0x02E0

typedef struct {
	float volt;
	float curr;
	float pow;
} __attribute__((packed)) cv_data_t;

cv_data_t cv_data;
uint8_t mdata[1 + sizeof(cv_data_t)];

volatile uint8_t new_data = 0;

// Intervals for advertising and connections
static simple_ble_config_t ble_config = {
    .platform_id       = 0x00,              // used as 4th octect in device BLE address
    .device_id         = DEVICE_ID_DEFAULT,
    .adv_name          = "Solar",       // used in advertisements if there is room
    .adv_interval      = MSEC_TO_UNITS(3000, UNIT_0_625_MS),
    .min_conn_interval = MSEC_TO_UNITS(500, UNIT_1_25_MS),
    .max_conn_interval = MSEC_TO_UNITS(1000, UNIT_1_25_MS)
};

void log_data(void* p_context) {
	new_data = 1;
}

static void adv_config_eddystone () {
	eddystone_adv(PHYSWEB_URL, NULL);
}

static void adv_config_data() {
	ble_advdata_manuf_data_t mandata;

	mdata[0] = CV_SENSE_SERVICE;

	memcpy(mdata+1, (uint8_t*) &cv_data, sizeof(cv_data_t));

	mandata.company_identifier = UMICH_COMPANY_IDENTIFIER;
	mandata.data.p_data = mdata;
	mandata.data.size = 1 + sizeof(cv_data_t);

	simple_adv_manuf_data(&mandata);
}

static void blink_red() {
	for(uint8_t i = 0; i < 200; i++) {
		led_on(LED_0);
		led_off(LED_0);
	}
}

static void blink_blue() {
	for(uint8_t i = 0; i < 200; i++) {
		led_on(LED_1);
		led_off(LED_1);
	}
}

static void blink_green() {
	for(uint8_t i = 0; i < 200; i++) {
		led_on(LED_2);
		led_off(LED_2);
	}
}

int main(void) {

	//initalize peripherals
	cvsense_init();
	rv3049_init();
	platform_init();

    // Setup BLE
    simple_ble_init(&ble_config);

	multi_adv_init(ADV_SWITCH_MS);
	multi_adv_register_config(adv_config_eddystone);
	multi_adv_register_config(adv_config_data);

	//setup timer
	simple_timer_init();

	//setup logger
	simple_logger_init("stest2.csv","a");
	simple_logger_log_header("%s,%s,%s,%s\n","Time","Voc","Isc","Estimated_Power");

	//start the timer
	simple_timer_start (10000, log_data);

	multi_adv_start();

    while (1) {

		if(new_data) {

			NRF_SPI1->ENABLE = (SPI_ENABLE_ENABLE_Enabled << SPI_ENABLE_ENABLE_Pos);
			rv3049_time_t time;
			rv3049_read_time(&time);

			float voltage = cvsense_get_voltage();
			cv_data.volt = voltage;

			float current = cvsense_get_current();
			cv_data.curr = current;

			cv_data.pow = current*voltage*0.7;

			blink_blue();
			if(simple_logger_log("%02d/%d %d:%d:%d,%f,%f,%f\n",time.month,time.days,time.hours,time.minutes,time.seconds,
																voltage,current,voltage*current*0.7)) {
				blink_red();
			} else {
				blink_green();
			}

			new_data = 0;
			NRF_SPI1->ENABLE = (SPI_ENABLE_ENABLE_Disabled << SPI_ENABLE_ENABLE_Pos);
		}

        power_manage();
    }
}

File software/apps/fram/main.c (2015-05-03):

/* Send an advertisement periodically
 */

#include <stdbool.h>
#include <stdint.h>
#include "nrf.h"
#include "nrf_gpio.h"
#include "ble_advdata.h"
#include "boards.h"
#include "nordic_common.h"
#include "softdevice_handler.h"
#include "ble_debug_assert_handler.h"
#include "led.h"
#include "fm25l04b.h"


#define IS_SRVC_CHANGED_CHARACT_PRESENT 0                                 /**< Include or not the service_changed characteristic. if not enabled, the server's database cannot be changed for the lifetime of the device*/
#define ADVERTISING_LED                 LED_0                             /**< Is on when device is advertising. */

#define USE_LEDS                        1

#define APP_CFG_NON_CONN_ADV_TIMEOUT    0                                 /**< Time for which the device must be advertising in non-connectable mode (in seconds). 0 disables timeout. */
#define NON_CONNECTABLE_ADV_INTERVAL    MSEC_TO_UNITS(500, UNIT_0_625_MS)   /**< The advertising interval for non-connectable advertisement (100 ms). This value can vary between 100ms to 10.24s). */


// Insert manufacturing things into the advertisement
#define APP_COMPANY_IDENTIFIER          0x11BB                            /**< Company identifier I made up */

#define APP_BEACON_INFO_LENGTH          0x09                              /**< Total length of information advertised by the Beacon. */
#define APP_ADV_DATA_LENGTH             0x07                              /**< Length of manufacturer specific data in the advertisement. */
#define APP_DEVICE_TYPE                 0x01                              /**< Just chose 0x01 */
#define APP_BEACON_DATA                 0x73, 0x71, 0x75, 0x61, \
                                        0x6c, 0x6c                          // "squall"

#ifndef APP_SQUALL_ID
#define APP_SQUALL_ID                   0x42
#endif

// information about the advertisement
ble_advdata_t                           advdata;
static ble_gap_adv_params_t             m_adv_params;                     /**< Parameters to be passed to the stack when starting advertising. */

static uint8_t m_beacon_info[APP_BEACON_INFO_LENGTH] =                  /**< Information advertised by the Beacon. */
{
    APP_DEVICE_TYPE,
    APP_ADV_DATA_LENGTH,
    APP_BEACON_DATA,
    APP_SQUALL_ID
};


/**@brief Function for error handling, which is called when an error has occurred.
 *
 * @warning This handler is an example only and does not fit a final product. You need to analyze
 *          how your product is supposed to react in case of error.
 *
 * @param[in] error_code  Error code supplied to the handler.
 * @param[in] line_num    Line number where the handler is called.
 * @param[in] p_file_name Pointer to the file name.
 */
void app_error_handler(uint32_t error_code, uint32_t line_num, const uint8_t * p_file_name)
{
    // This call can be used for debug purposes during application development.
    // @note CAUTION: Activating this code will write the stack to flash on an error.
    //                This function should NOT be used in a final product.
    //                It is intended STRICTLY for development/debugging purposes.
    //                The flash write will happen EVEN if the radio is active, thus interrupting
    //                any communication.
    //                Use with care. Un-comment the line below to use.
    // ble_debug_assert_handler(error_code, line_num, p_file_name);

    // On assert, the system can only recover on reset.
    NVIC_SystemReset();
}


/**@brief Callback function for asserts in the SoftDevice.
 *
 * @details This function will be called in case of an assert in the SoftDevice.
 *
 * @warning This handler is an example only and does not fit a final product. You need to analyze
 *          how your product is supposed to react in case of Assert.
 * @warning On assert from the SoftDevice, the system can only recover on reset.
 *
 * @param[in]   line_num   Line number of the failing ASSERT call.
 * @param[in]   file_name  File name of the failing ASSERT call.
 */
void assert_nrf_callback(uint16_t line_num, const uint8_t * p_file_name)
{
    app_error_handler(0xDEADBEEF, line_num, p_file_name);
}

// Setup TX power and the device name
static void gap_params_init(void)
{
    uint32_t                err_code;
    ble_gap_conn_sec_mode_t sec_mode;

    // Set the power. Using really low (-30) doesn't really work
    sd_ble_gap_tx_power_set(4);

    // Make the connection open (no security)
    BLE_GAP_CONN_SEC_MODE_SET_OPEN(&sec_mode);

    // Set the name of the device so its easier to find
    err_code = sd_ble_gap_device_name_set(&sec_mode,
                                          (const uint8_t *)DEVICE_NAME,
                                          strlen(DEVICE_NAME));
    APP_ERROR_CHECK(err_code);
}


/**@brief Function for initializing the Advertising functionality.
 *
 * @details Encodes the required advertising data and passes it to the stack.
 *          Also builds a structure to be passed to the stack when starting advertising.
 */
static void advertising_init(void)
{
    uint32_t                  err_code;

    // Use the simplest send adv packets only mode
    uint8_t                   flags = BLE_GAP_ADV_FLAG_BR_EDR_NOT_SUPPORTED;

    // More manufacturing only stuff that might get added back in
    ble_advdata_manuf_data_t  manuf_specific_data;

	manuf_specific_data.company_identifier = APP_COMPANY_IDENTIFIER;
	uint8_t buf;
	fm25l04b_read(0x00,1,&buf);

     manuf_specific_data.data.p_data        = &buf;
     manuf_specific_data.data.size          = 1;

    // Build and set advertising data.
    memset(&advdata, 0, sizeof(advdata));

    advdata.name_type               = BLE_ADVDATA_FULL_NAME;
    advdata.flags.size              = sizeof(flags);
    advdata.flags.p_data            = &flags;
    advdata.p_manuf_specific_data   = &manuf_specific_data;

    err_code = ble_advdata_set(&advdata, NULL);
    APP_ERROR_CHECK(err_code);

    // Initialize advertising parameters (used when starting advertising).
    memset(&m_adv_params, 0, sizeof(m_adv_params));

    m_adv_params.type        = BLE_GAP_ADV_TYPE_ADV_NONCONN_IND;
    m_adv_params.p_peer_addr = NULL;                             // Undirected advertisement.
    m_adv_params.fp          = BLE_GAP_ADV_FP_ANY;
    m_adv_params.interval    = NON_CONNECTABLE_ADV_INTERVAL;
    m_adv_params.timeout     = APP_CFG_NON_CONN_ADV_TIMEOUT;
}


/**@brief Function for starting advertising.
 */
static void advertising_start(void)
{
    uint32_t err_code;

    err_code = sd_ble_gap_adv_start(&m_adv_params);
    APP_ERROR_CHECK(err_code);
}
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

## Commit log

2015-03-27 copied original atum board to atum-le
    [atum-le.brd, atum-le.sch]
2015-03-27 improved signal routing and mapping
    [atum-le.brd, atum-le.sch]
2015-04-18 finished up schematic and did more routing
    [atum-le.brd, atum-le.sch]
2015-04-18 added jtag, board routed but not DRCd
    [atum-le.brd, atum-le.sch]
2015-04-19 fixed all drc errors
    [atum-le.brd]
2015-04-19 updated the lbr file to match le pin names
2015-04-19 changed lbr to allow for prog holes
2015-04-20 fixed programming breakout, moved silk
    [atum-le.brd, atum-le.sch]
2015-04-20 moved a few vias
    [atum-le.brd]
2015-04-21 finished routing cleanup and silk
    [atum-le.brd]
2015-04-21 changed name to nucleum
    [nucleum.brd, nucleum.sch]
2015-04-21 finished layout and routing
    [nucleum.brd]
2015-04-21 regain board annotation, finished/fix annotation erros
    [nucleum.brd, nucleum.sch]
2015-04-21 renerated bom and renamed parts to ascending order
    [nucleum.csv]
2015-04-21 sent files to sunstone
    [nucleum.brd]
2015-04-23 added 3 led blink app
2015-04-28 got the rv3049 driver compiling. still untested
2015-04-28 added untested fram driver
2015-05-03 fixed examples so that they work with current hardware
    [fm25l04b.c, main.c, nucleum.h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]
2015-06-02 added excel format BOM
    [nucleum_bom.xlsx]
2015-06-03 updated bom
    [nucleum_bom.xlsx]
2015-06-11 final bom update
    [nucleum_bom.xlsx]
2015-06-11 added panelized gerbers
2015-11-24 add uart test app
2016-06-07 Will found a bug in the Nucleum library file where SWDIO and unused are switched
2016-06-09 started a logger nucleum board that accepts squall shields
    [nucleum_logger.brd, nucleum_logger.sch]
2016-06-09 fixed the i2c pin labels on the library part
2016-06-09 added working timer example for sdk 10
2016-06-09 main file currently running on the first signpost deployment
2016-06-09 did some final changes to the nucleum logger board
    [nucleum_logger.brd, nucleum_logger.sch]
2016-06-09 fixed some attributes
    [nucleum_logger.sch]
2016-06-10 ran drc on the board
    [nucleum_logger.brd]
2016-06-10 fixed the solar panel test code to not break the NRF
    [main.c]
2016-06-10 added a version of nucleum logger to be shipped
    [nucleum_logger.csv, nucleum_logger.xls]
2016-06-12 added the capacitive touch app
2016-06-12 added the door schematic and the code for the PIR protection filtering
    [capacitive_touch.sch]
2016-06-12 changed the PIR sensor to an interrupt
2016-06-13 added the plotting and data from a test
    [test2.csv]
2016-06-15 added the new solar panel test
    [test3.csv]
2016-06-15 setup spi every transfer - slow but reliable
2016-06-15 added the current sense driver and fixed a simple logger bug
    [cvsense.c, main.c, nucleum_logger.h]
2016-06-16 removed some of the data processing stuff out into another folder
    [test2.csv, test3.csv]
2016-06-16 made a rev_A folder
    [nucleum_logger.brd, nucleum_logger.csv, nucleum_logger.sch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]
2016-06-17 added rev_B of the nucleum logger board
    [nucleum_logger.brd, nucleum_logger.csv, nucleum_logger.sch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]
2016-06-17 write extra byte after command per sd spec
    This effectively reduces power consumption from 15ma to 250ua between writes.
    the line of code was commented out with a warn ("may cause errors") message
    so this might need to be removed, but it worked on the Sandisk Ultra during
    my testing. Power savings are significant so it should be worth it.
2016-06-17 added a rev_B of nucleum logger - we go to production
    [nucleum_logger.brd, nucleum_logger.csv, nucleum_logger.sch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]
2016-06-23 added a new pin for logger
2016-06-23 updated voltage current logger
2016-06-23 updated the current/voltage sense board to update every reading
2016-06-26 added the sd writing in thread context
2016-07-01 added power_manage, saves a few ma
2016-07-11 added code to diable current amplifier
2016-07-11 disabling spi when not using it
2016-07-12 fixed the disable cvsense code
    [cvsense.c]
2016-07-31 adding code for the replay board
2016-11-25 added code for voltage current logger b
    It does build
    It is completely untested. I could have messed up a pin
    Current or voltage equations could be wrong.
    Maybe nothing works at all
    [cvsense_b.c, main.c, nucleum_logger_b.h]
2016-12-02 fixed a bug in the SHDN timing
    [cvsense_b.c]
2017-01-07 updated software for cvsense boards
2017-01-09 fixed the resistance value of cvsenseb
    [cvsense_b.c]
2017-05-15 fixed some wrong digikey numbers
    [nucleum_bom.xlsx]

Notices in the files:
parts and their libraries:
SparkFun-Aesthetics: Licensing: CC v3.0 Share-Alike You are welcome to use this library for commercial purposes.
